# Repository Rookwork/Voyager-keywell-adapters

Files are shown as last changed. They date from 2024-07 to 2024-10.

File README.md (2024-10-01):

# Voyager keywell adapters
3D-printable adapters to curve the ZSA Voyager keycaps

Here you'll find various files you can use to print adapters that will make the Voyager keycaps into more of a bowl shape. These adapters may also work for other boards, but the focus of the design is the Voyager. 

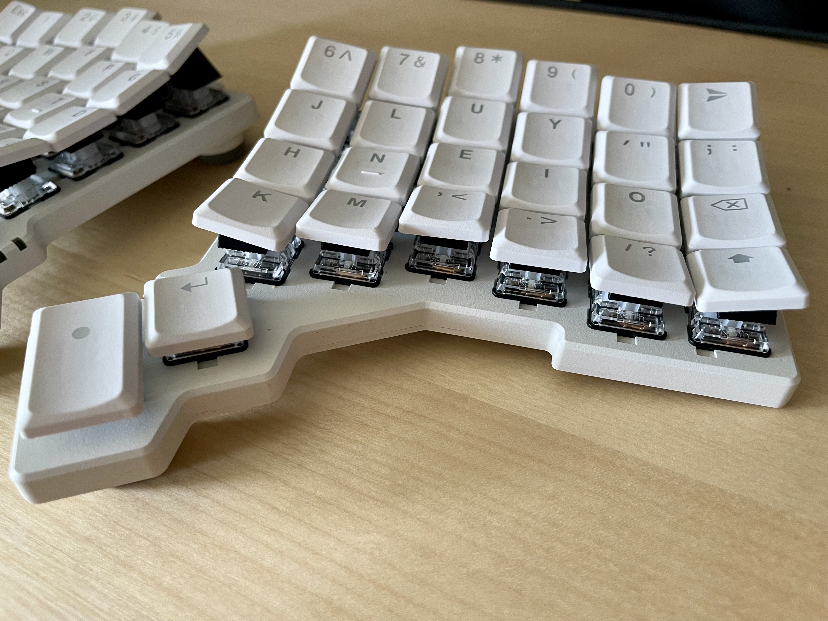
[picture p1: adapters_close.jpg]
Keywell adapters


A few notes about this print:
1. It can be challenging due to the small parts and tight tolerances involved. I highly suggest printing a couple of adapters first to test your printer before printing the full set.
2. The adapters have small indents on each side at the keycap end to help remove them. You can use a standard switch puller. However, please be careful when installing and removing these. Choc keycap stems are fragile and they can and will break if you're not careful to pull the adapters straight off the keycaps. Do not pull at an angle!
3. The adapters in the complete file are arranged to match up with the Voyager as though it were laying with its keycaps down. That means that the top right adapter goes in the top left switch as you're looking down at the Voyager, the top left adapter goes in the top right switch, etc. 

Print settings guidance:
- I used PLA since that's what I had and it worked fine, but ABS might be a better choice if you have access to some. 
- I found a warmer bed temperature of 65-70 C (using PLA) helped cut down on the spaghetti failures I sometimes got. 
- 0.2mm layer height
- No supports needed
- 100% infill for stability

If you need STL files, please see the separate readme in the STL files folder. 

As with any non-official ZSA accessory design, ZSA cannot provide warranty support if something goes wrong. I am providing this design free of charge and also not promising any sort of warranty or support personally. Again, please be careful if you try out this design. 

Special thanks to Thomas Tse (tomtomthing) for the [design inspiration](https://www.thingiverse.com/thing:5932496), Voyager user Joseph Lee for sharing his version of this, and to ZSA CEO Erez for testing the design and providing feedback. 

Thanks as well to user UhForgot on Reddit for [being the first person](https://www.reddit.com/r/zsaVoyager/comments/1fjhtz1/1_year_with_the_zsa_voyager/) (that I've seen) to try this out!

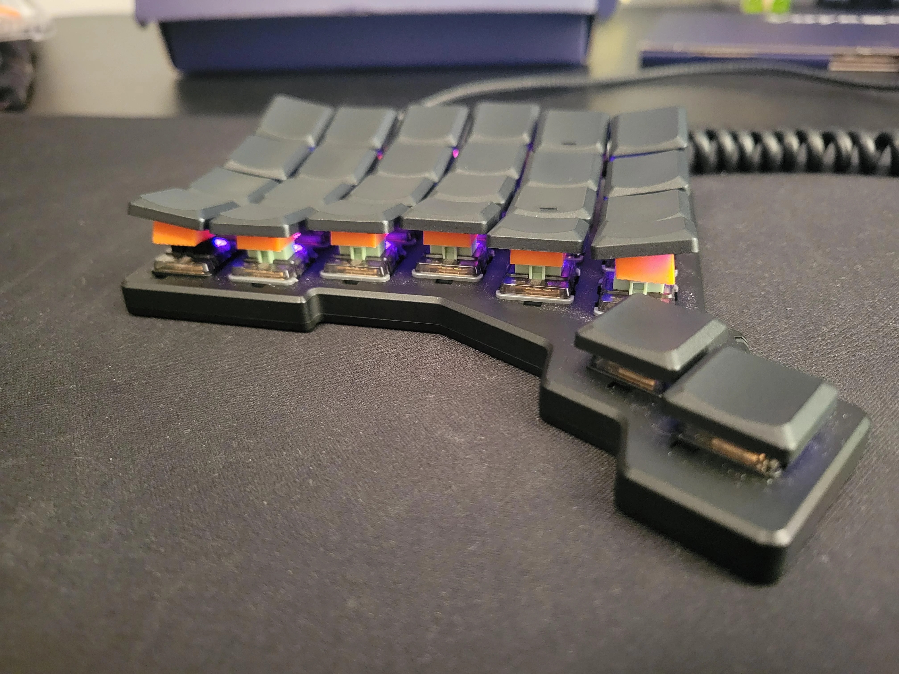
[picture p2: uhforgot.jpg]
u/UhForgot's Voyager


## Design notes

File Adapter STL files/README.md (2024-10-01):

# Voyager keywell adapters STL files

If you are ordering these adapters to be printed for you, you may need STL files rather than 3mf files. This is doable, but there are a lot of different individual models to coordinate, so be sure to double-check your order. Below is a diagram of the Voyager rows and columns labeled according to the stl file names. 

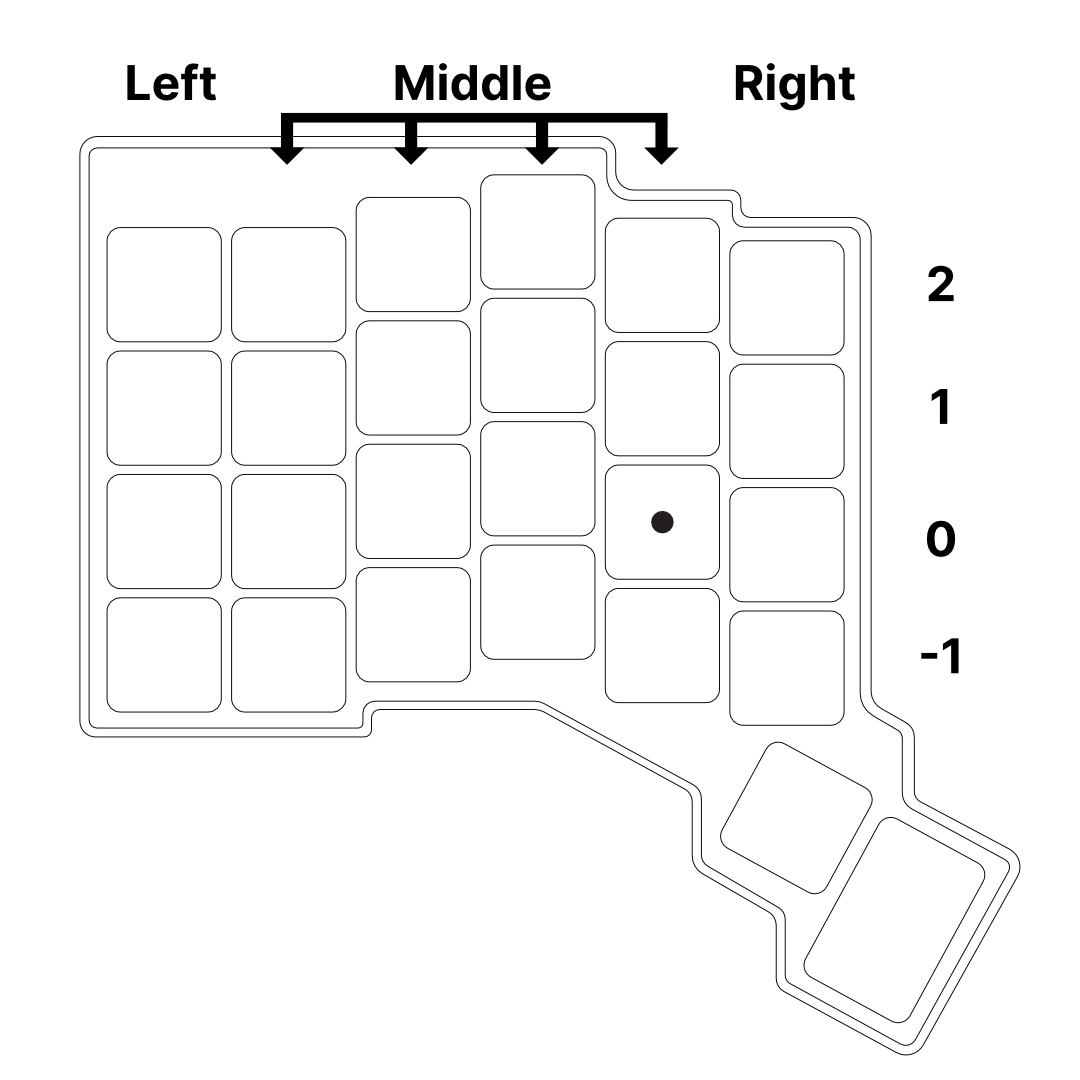
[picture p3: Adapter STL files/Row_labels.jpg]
Voyager rows and columns labeled


A complete set of adapters for both halves of the Voyager will need these parts:
- 2x Left -1
- 2x Left 0
- 2x Left 1
- 2x Left 2
- 2x Right -1
- 2x Right 0
- 2x Right 1
- 2x Right 2
- 8x Middle -1
- 8x Middle 0
- 8x Middle 1
- 8x Middle 2

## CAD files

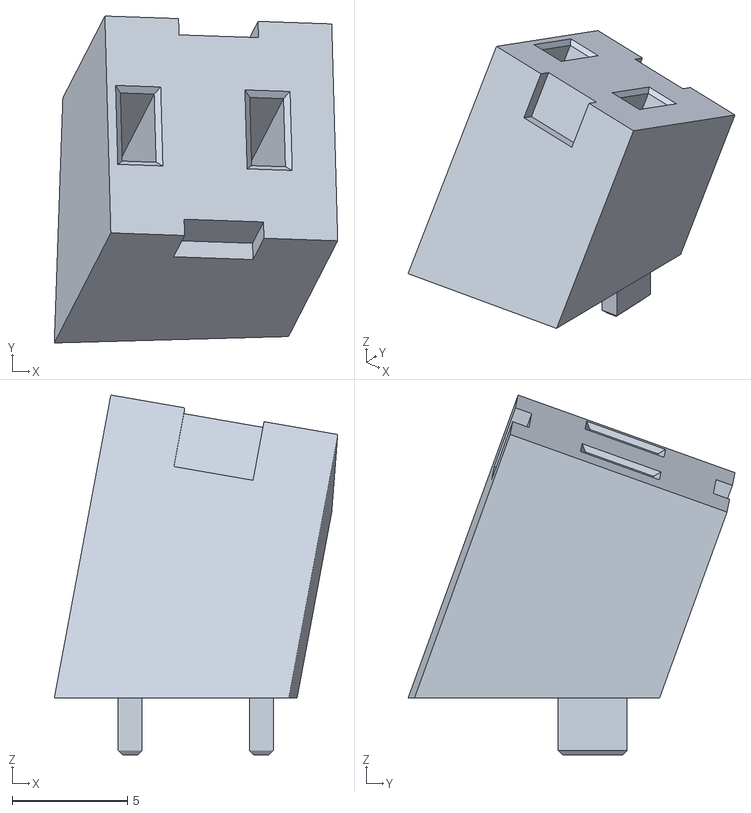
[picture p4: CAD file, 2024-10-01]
Adapter STL files/Right_2.stl
12.3 x 14.2 x 15.6

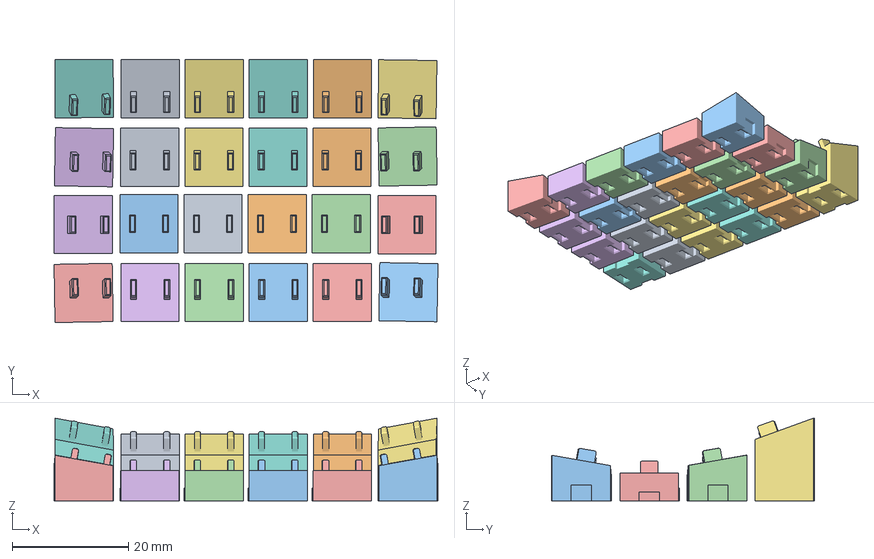
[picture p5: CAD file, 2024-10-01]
Voyager_keywell_single_half.3mf
66.0 x 45.2 x 14.2 mm
0_degree_mid_final.stl x 4
0_degree_right_final.stl
0_degree_left_final.stl
10_degree_mid_final.stl x 8
20_degree_mid_final.stl x 4
10_degree_left_lower_final.stl
10_degree_left_upper_final.stl
10_degree_right_lower_final.stl
10_degree_right_upper_final.stl
20_degree_left_final.stl
20_degree_right_final.stl

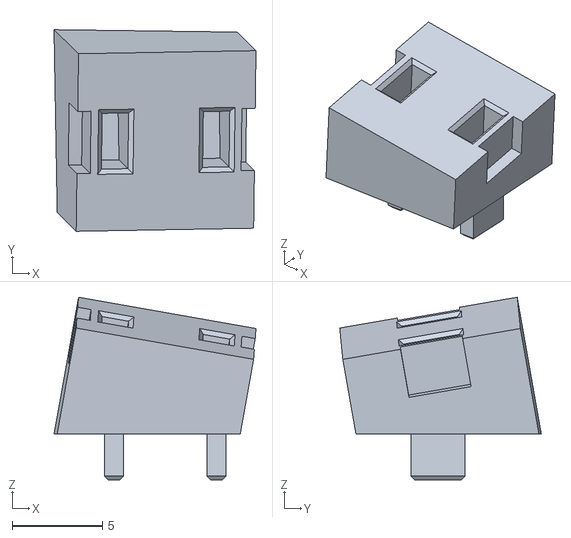
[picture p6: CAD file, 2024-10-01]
Adapter STL files/Right_-1.stl
11.2 x 11.2 x 10.1

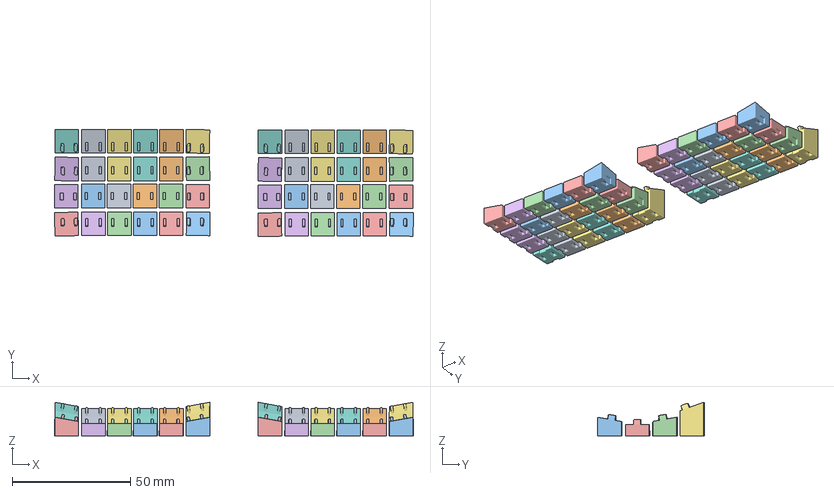
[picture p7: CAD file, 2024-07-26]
Voyager_keywell_two_halves.3mf
152.0 x 45.4 x 14.2 mm
0_degree_mid_final.stl x 8
0_degree_right_final.stl x 2
0_degree_left_final.stl x 2
10_degree_mid_final.stl x 16
20_degree_mid_final.stl x 8
10_degree_left_lower_final.stl x 2
10_degree_left_upper_final.stl x 2
10_degree_right_lower_final.stl x 2
10_degree_right_upper_final.stl x 2
20_degree_left_final.stl x 2
20_degree_right_final.stl x 2

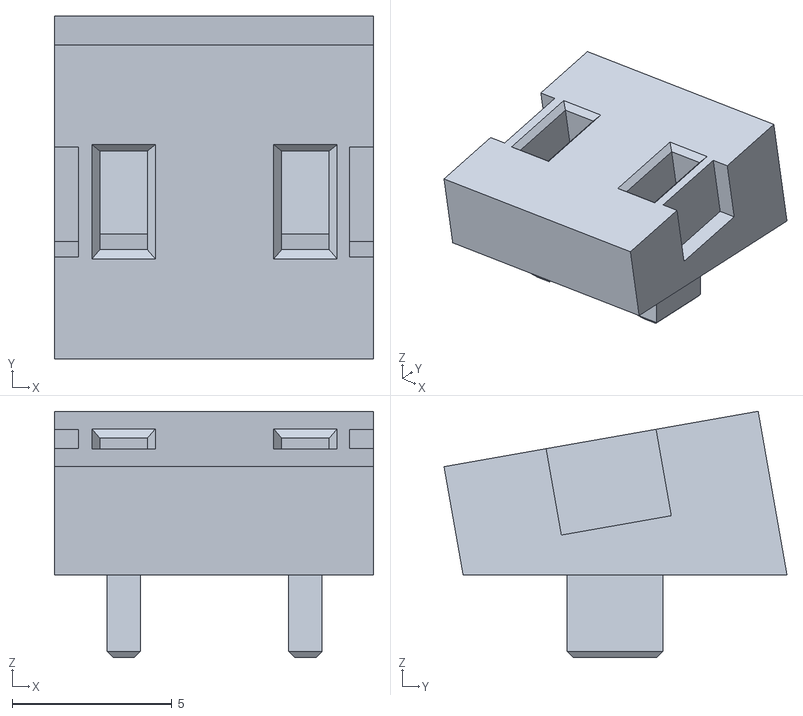
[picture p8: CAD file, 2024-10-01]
Adapter STL files/Middle_-1.stl
10.0 x 10.8 x 7.72

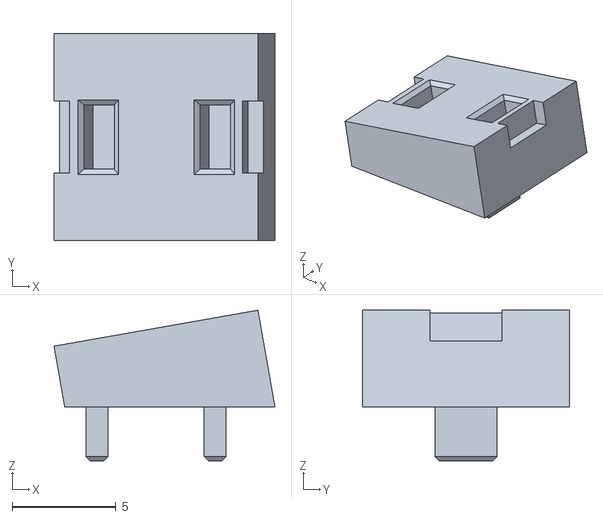
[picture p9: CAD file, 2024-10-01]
Adapter STL files/Left_0.stl
10.7 x 10.0 x 7.27

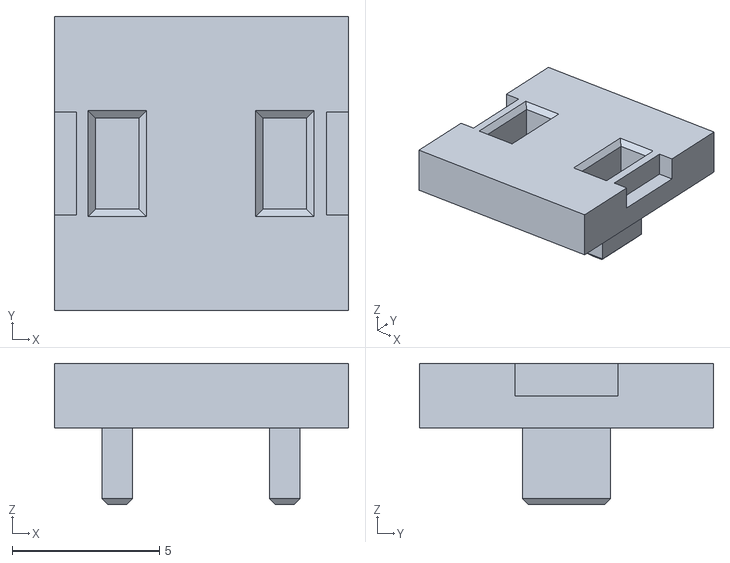
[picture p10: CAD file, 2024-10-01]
Adapter STL files/Middle_0.stl
10.0 x 10.0 x 4.80

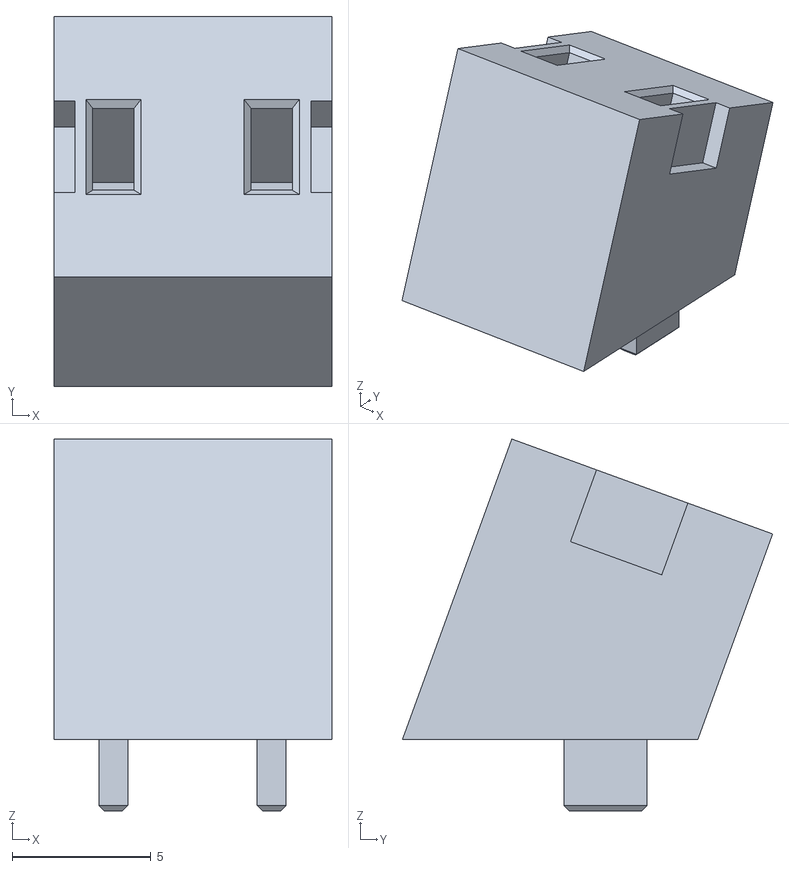
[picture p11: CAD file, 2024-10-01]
Adapter STL files/Middle_2.stl
10.0 x 13.3 x 13.4

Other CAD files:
Adapter STL files/Left_-1.stl
Adapter STL files/Left_2.stl
Adapter STL files/Right_0.stl
Adapter STL files/Left_1.stl
Adapter STL files/Middle_1.stl
Adapter STL files/Right_1.stl

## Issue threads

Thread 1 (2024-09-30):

3MF cannot be read / converted to STL

rpnfan, 2024-09-30:
Many services do only except STL files. The 3MF should be able to convert to STL, but all tools I tried gave an error message that the filetype is not correct (not 3MF)!? Any ideas how to fix that?

Rookwork, 2024-10-01:
Interesting that 3mf isn't supported! Well, no problem. I just added the STL files for each adapter. Just be careful to double-check your quantities because there are several different files for each part of the board.

rpnfan, 2024-10-01:
Thanks a lot, that is great! :-)

OneGraund, 2024-11-11:
Hey, would be nice if you could also upload stl file for both halves :) so that people don't drag and drop 60 models in their god awful slicers (couldn't be me)

Closed 2024-10-01.

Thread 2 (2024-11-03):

Moonlander

naudor, 2024-11-03:
Hi, can you explain how to adapt it to the Moonlander keyboard? Would a complete rework be necessary, or could it be done with just some adapters?

Thanks

Rookwork, 2024-11-04:
Hi! It wouldn't really make sense to try to adapt these to a Moonlander — it would be better to make a new set of adapters to work with MX switches. That said, I wouldn't really recommend that either for a couple of reasons:

1. The Choc switches are short so they can tolerate a little extra height from these adapters without getting comically tall. The MX switches are already full-height, so adding even more height would get kind of silly.
2. The incline of these adapters is not super extreme. You would get a similar effect from just using a sculpted set of keycaps, like the [official blank set](https://www.zsa.io/moonlander/accessories) for the Moonlander.

Hope that helps!

Closed 2024-11-04.

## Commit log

2024-10-01 Updated 3mf files
    [Voyager_keywell_single_half.3mf, Voyager_keywell_two_halves.3mf]
2024-10-01 Added STL files
    [Left_-1.stl, Left_0.stl, Left_1.stl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]
